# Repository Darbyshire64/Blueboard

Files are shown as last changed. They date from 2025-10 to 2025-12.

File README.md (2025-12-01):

# Blueboard
A Custom ANSI 109 Keyboard. Featuring:   
  - .91inch OLED display
  - Two Potentiomiters
  - 5 Macro Keys

https://blueprint.hackclub.com/projects/1084

## Important Notes About this project
 - If a Component is listed as $0.00 it is already owned by me
 - The BOM says RP2040 But the Schematics say ESP-32 C3 this is because i change mcu mid project however the xiao modules pinout are identical.
 - My Journal.md is outdated but the one on the blueprint project is up todate. the bot seemed to stop updating it automaticly.

### BOM
Alot of these components i or a freind has so i dont need to buy them and i can print the  case my self.

-----------------------------------------
| PRICE | QTY | ITEM |LINK |
|---|-----|---|-----|
| $0.00 | x1  |XIAO RP2040 | |
| $0.00 | x2  |MCP23017 GPIO Expander (SPDIP) | |
| $0.00 | x109| 1N2007 (DO-35 | |
| $0.00 | x2  |Rotary Encoder Switches| |
| $0.00 | x1  |.91inch OLED | |
|-------|-----|--Case-------------|-----|
| $0.00 | x1  |3D Printed Case | |
|------|------|--Key's-------------|-----|
| $24.00| x1  | Key Cap Set | <a href="https://www.aliexpress.com/item/1005007817761888.html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£"> LINK </a> |
| $16.20| x109 | Switches |<a href="https://www.aliexpress.com/item/1005002378701948.html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">LINK </a> |
|$3.68  | x1 | Key Stabalizers Set  | <a href="https://www.aliexpress.com/item/1005004229140548.html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"> LINK </a> |
|-------|------| PCB COSTS --------|------|
|$33.40 | x1 | PCB | |
|$18.63 | x1 | GSDL SHIPING | |
|-$20 | | BP Coupon | |
|-------|------|-------------------|------|
| $75.91 | | TOTAL With Coupon| |
| $95.91 | | TOTAL Without Coupon| |

## Renders
Render2
Render1
Render5
Render4
Render3

## Case






## PCB



## Themeing

Blueboard is Themed and designed to my specific Liking. It features a Blue, Black and Brown Colour scheme. With a Zero RGB Aproach.

#### <a href="https://www.aliexpress.com/item/1005007817761888.html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"> Keycaps </a>


#### <a href="https://www.keyboard-layout-editor.com/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'&_c=%23ab8649&t=%231c3b94&w:2.25%3B&=Enter&_x:3.5&c=%231c3b94&t=%23ab8649%3B&=4%0A%E2%86%90&=5&=6%0A%E2%86%92%3B&@_x:0.25&c=%23cccccc&t=%23000000&a:7%3B&=&_x:0.25&c=%232b2b2b&t=%23ab8649&a:4&w:2.25%3B&=Shift&_c=%231c3b94%3B&=Z&=X&=C&=V&=B&=N&=M&=%3C%0A,&=%3E%0A.&=%3F%0A%2F%2F&_c=%232b2b2b&w:2.75%3B&=Shift&_x:1.25&c=%23ab8649&t=%231c3b94%3B&=%E2%86%91&_x:1.25&c=%231c3b94&t=%23ab8649%3B&=1%0AEnd&=2%0A%E2%86%93&=3%0APgDn&_c=%23ab8649&t=%231c3b94&h:2%3B&=Enter%3B&@_x:0.25&c=%23cccccc&t=%23000000&a:7%3B&=&_x:0.25&c=%232b2b2b&t=%23ab8649&a:4&w:1.25%3B&=Ctrl&_w:1.25%3B&=Win&_w:1.25%3B&=Alt&_c=%23ab8649&t=%231c3b94&a:7&w:6.25%3B&=&_c=%232b2b2b&t=%23ab8649&a:4&w:1.25%3B&=Alt&_w:1.25%3B&=Win&_w:1.25%3B&=Menu&_w:1.25%3B&=Ctrl&_x:0.25&c=%23ab8649&t=%231c3b94%3B&=%E2%86%90&=%E2%86%93&=%E2%86%92&_x:0.25&c=%231c3b94&t=%23ab8649&w:2%3B&=0%0AIns&=.%0ADel"> Key Layout </a> 
keyboard-layout(2)
blueboard



## To Do
  - [X] PCB
    - [X] Deisign Schematic
      - [X] Switches
      - [X] RGB
      - [X] OLED
      - [X] Potentomiters
      - [X] MCU
      - [X] GPIO Expander 
    - [X] Design PCB
    - [X] Add Artwork
  - [ ] Export BOM to CSV
  - [X] Design Case
  - [X] Complete BOM
  - [ ] Write Skeleton Firmware (KMK)

497498089-6dd5f2bd-8309-466f-af9c-b98fabe8da96

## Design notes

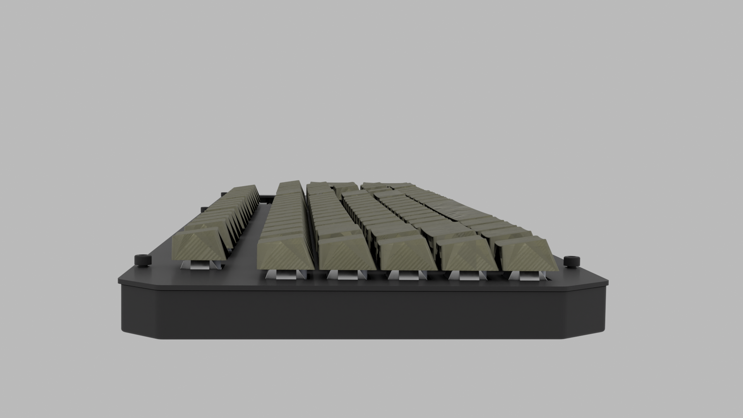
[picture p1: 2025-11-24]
Assets/Render/Render4.png

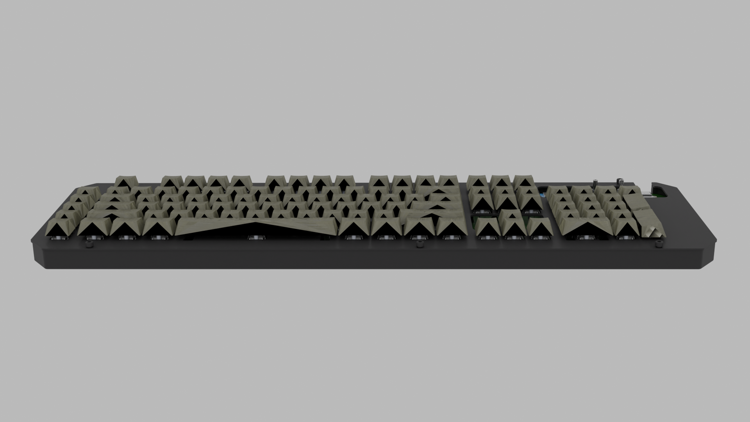
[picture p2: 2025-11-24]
Assets/Render/Render3.png

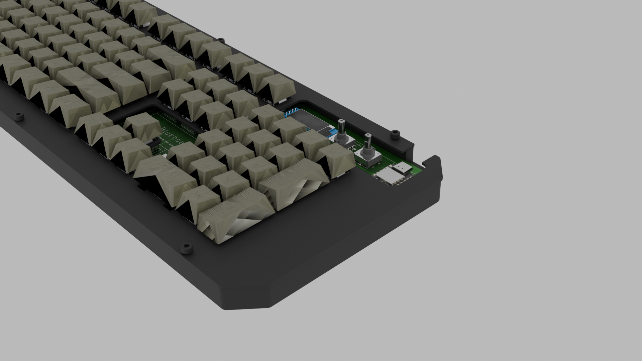
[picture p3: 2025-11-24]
Assets/Render/Render2.png

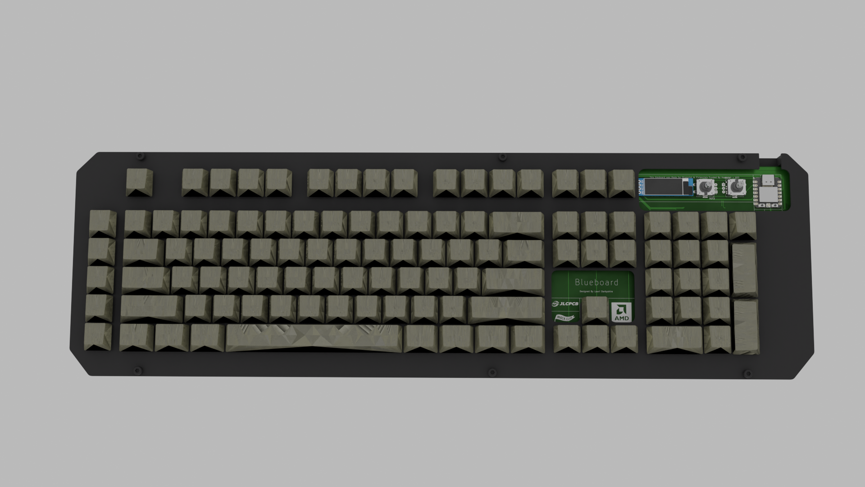
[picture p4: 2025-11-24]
Assets/Render/Render1.png

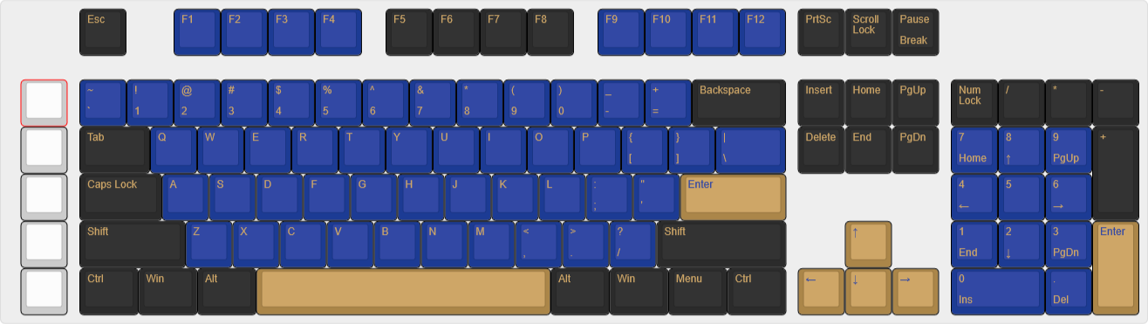
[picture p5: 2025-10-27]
Assets/blueboard-keys-only.png

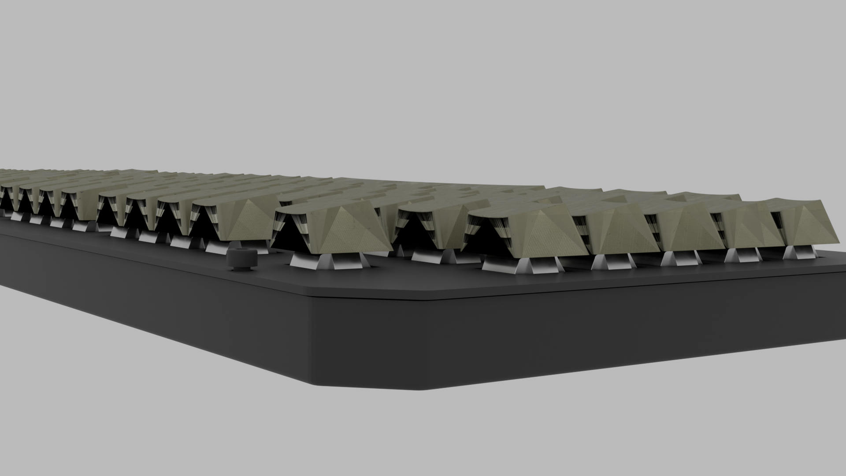
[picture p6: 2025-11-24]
Assets/Render/Render5.png

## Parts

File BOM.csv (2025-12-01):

PRICE | QTY | ITEM | LINK
$0.00 | x1 | XIAO RP2040
$0.00 | x2 | MCP23017 GPIO Expander (SPDIP)
$0.00 | x109 | 1N2007 (DO-35)
$0.00 | x2 | Rotary Encoder Switches
$0.00 | x1 | .91inch OLED
$0.00 | x1 | 3D Printed Case
$24.00 | x1 | Key Cap Set | https://www.aliexpress.com/item/1005007817761888.html
$16.20 | x109 | Switches | https://www.aliexpress.com/item/1005002378701948.html
$3.68 | x1 | Key Stabalizers Set | https://www.aliexpress.com/item/1005004229140548.html
$33.40 | x1 | PCB
$18.63 | x1 | GSDL SHIPING
-$20 |  | BP Coupon
$75.91 |  | TOTAL With Coupon
$95.91 |  | TOTAL Without Coupon

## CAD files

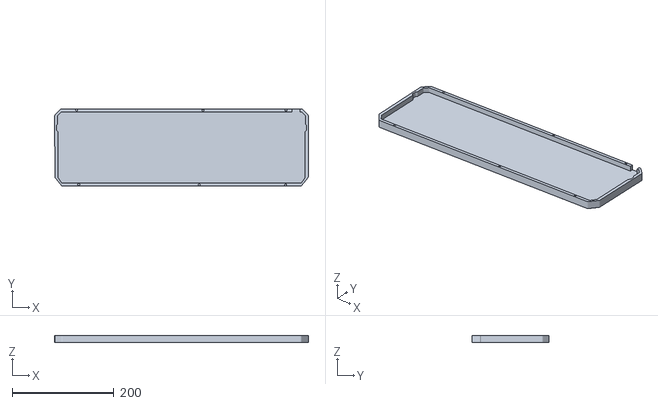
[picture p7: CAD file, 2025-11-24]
Case/CaseBottom.stl
499.5 x 152.0 x 14.7

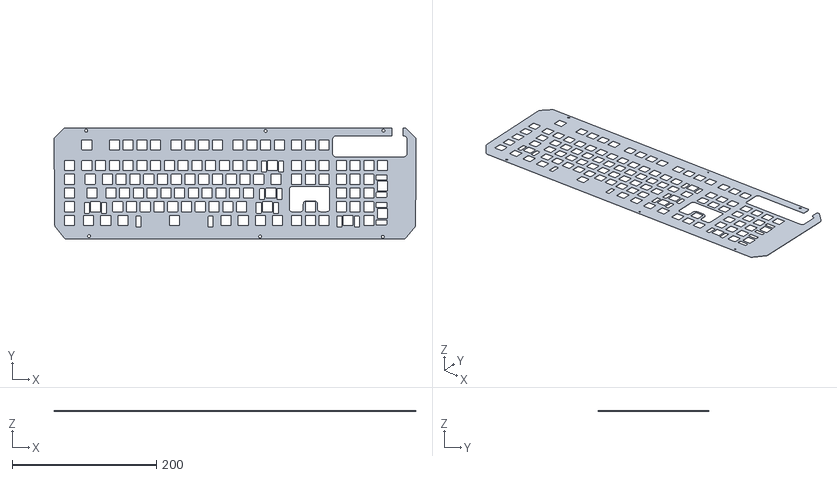
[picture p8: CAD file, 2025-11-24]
Case/Plate.stl
501.5 x 153.7 x 1.50

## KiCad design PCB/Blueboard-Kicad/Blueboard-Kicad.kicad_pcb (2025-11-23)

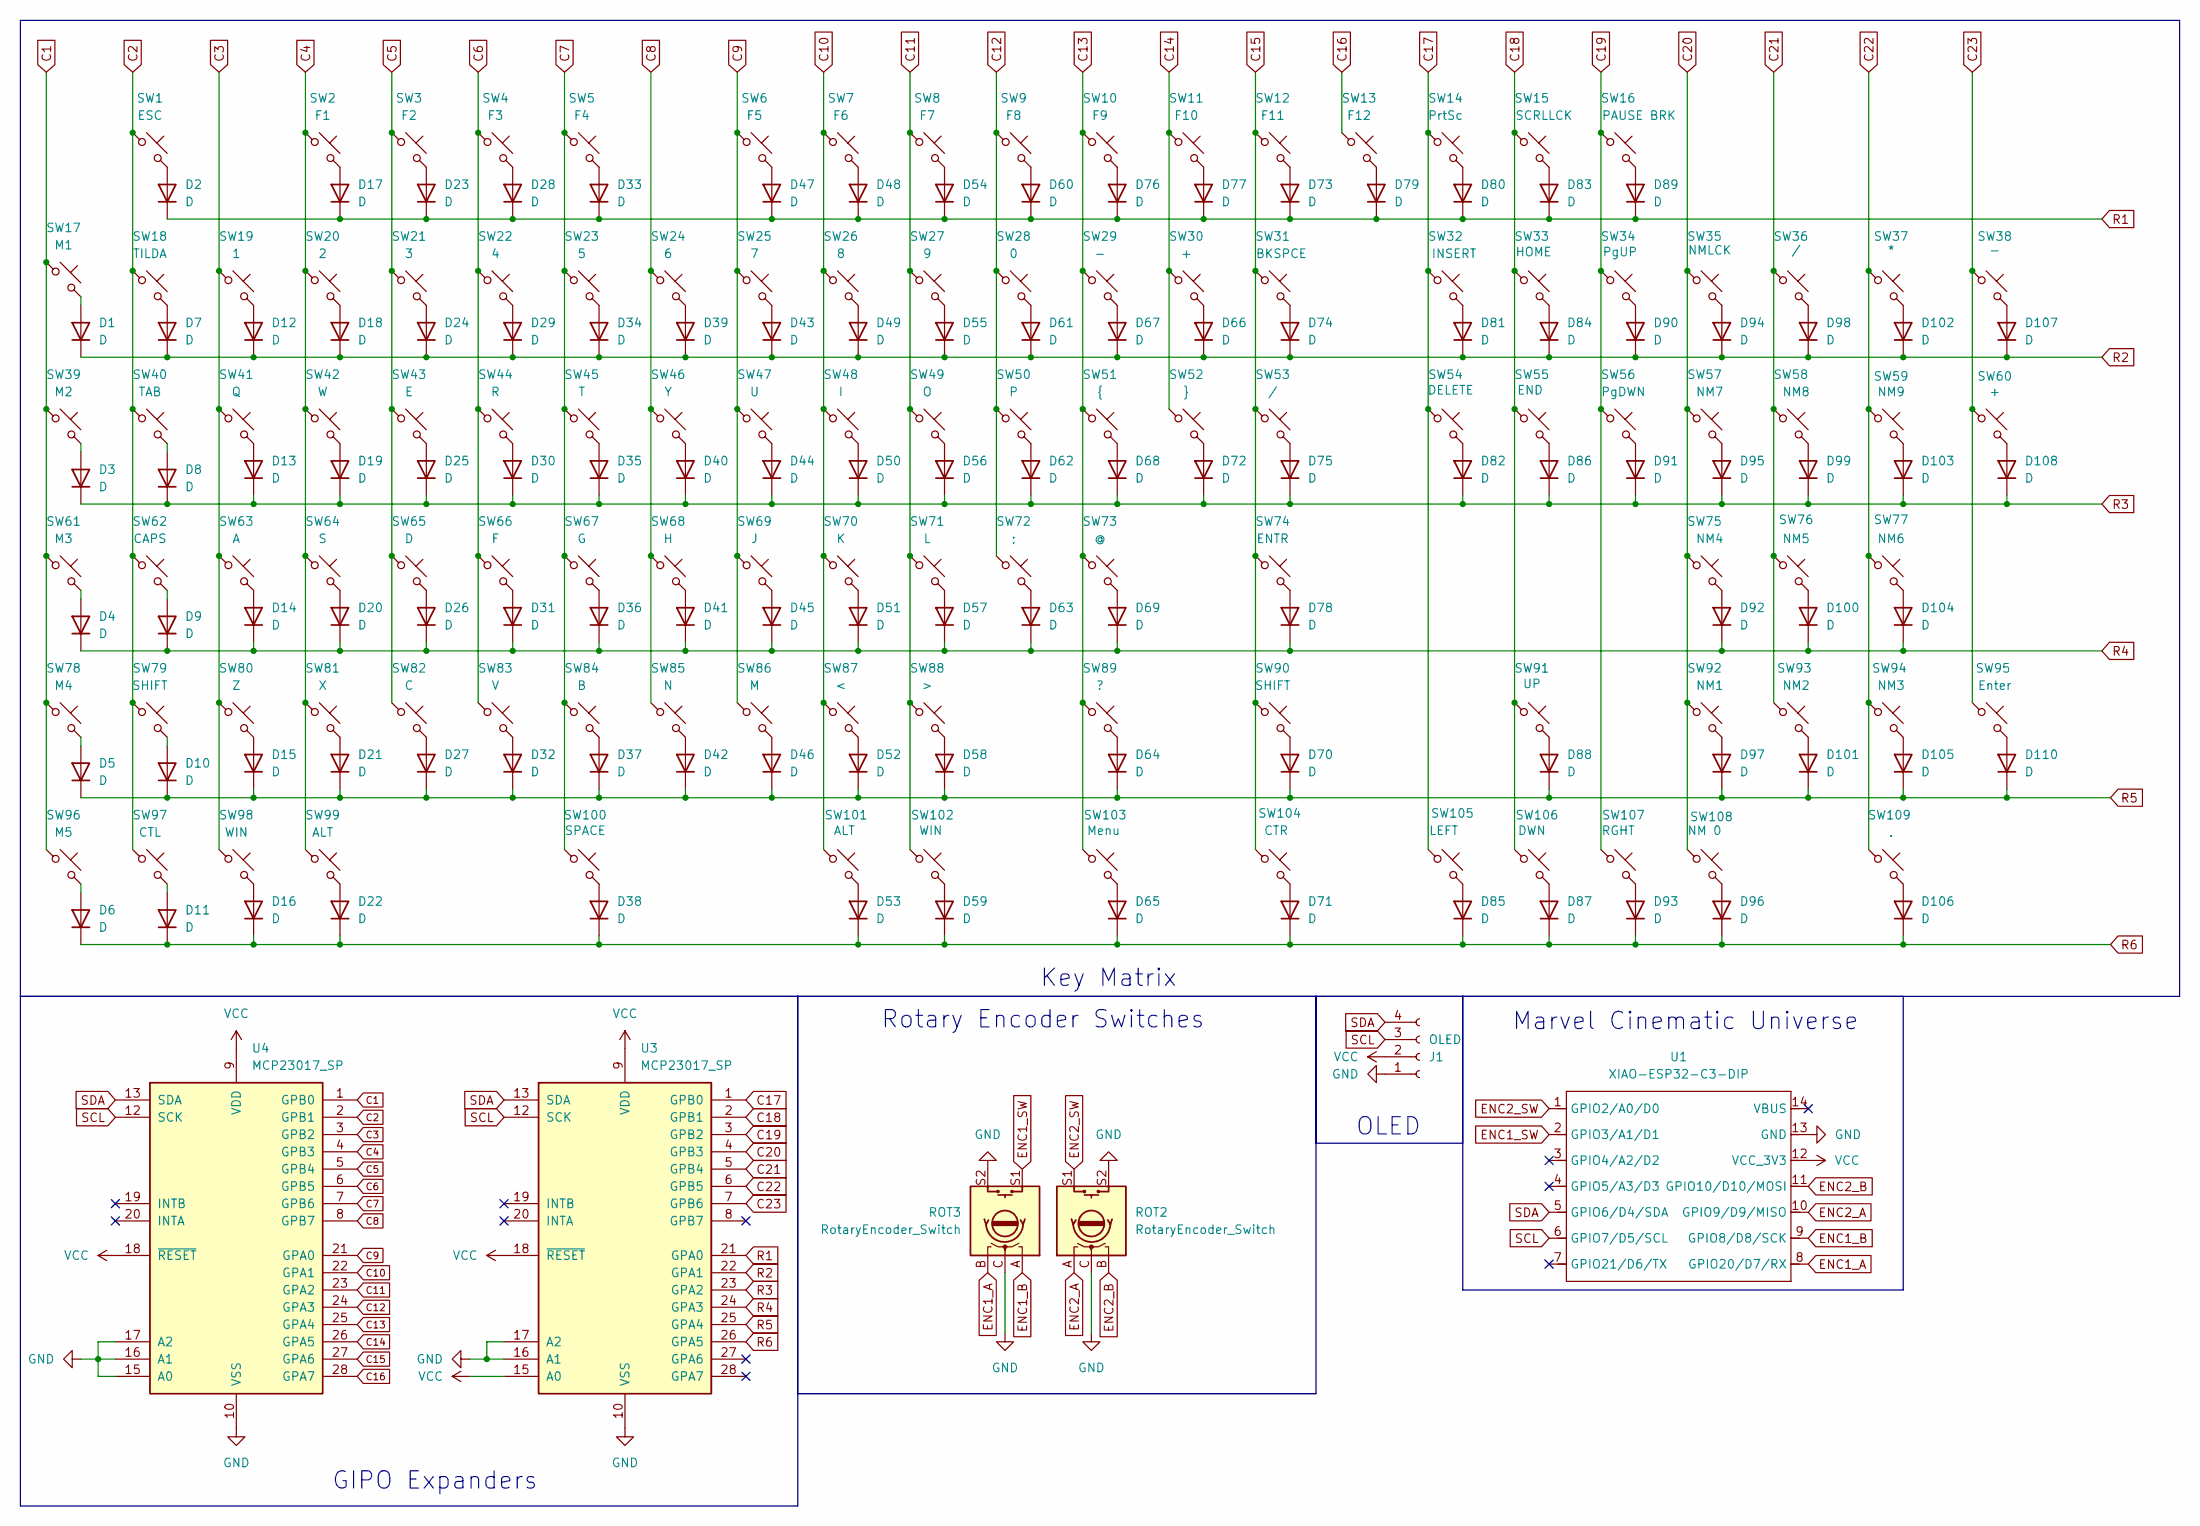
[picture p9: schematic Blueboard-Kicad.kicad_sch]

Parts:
D1, D2, D3, D4, D5, D6, D7, D8, D9, D10, D11, D12, D13, D14, D15, D16, D17, D18, D19, D20, D21, D22, D23, D24, D25, D26, D27, D28, D29, D30, D31, D32, D33, D34, D35, D36, D37, D38, D39, D40, D41, D42, D43, D44, D45, D46, D47, D48, D49, D50, D51, D52, D53, D54, D55, D56, D57, D58, D59, D60, D61, D62, D63, D64, D65, D66, D67, D68, D69, D70, D71, D72, D73, D74, D75, D76, D77, D78, D79, D80, D81, D82, D83, D84, D85, D86, D87, D88, D89, D90, D91, D92, D93, D94, D95, D96, D97, D98, D99, D100, D101, D102, D103, D104, D105, D106, D107, D108, D110: D; D_DO-41_SOD81_P7.62mm_Horizontal
J1: OLED; SSD1306-0.91-OLED-4pin-128x32
ROT2, ROT3: RotaryEncoder_Switch; RotaryEncoder_Alps_EC11E-Switch_Vertical_H20mm_MountingHoles
SW1: ESC; SW_Cherry_MX1A_1.00u_PCB
SW2: F1; SW_Cherry_MX1A_1.00u_PCB
SW3: F2; SW_Cherry_MX1A_1.00u_PCB
SW4: F3; SW_Cherry_MX1A_1.00u_PCB
SW5: F4; SW_Cherry_MX1A_1.00u_PCB
SW6: F5; SW_Cherry_MX1A_1.00u_PCB
SW7: F6; SW_Cherry_MX1A_1.00u_PCB
SW8: F7; SW_Cherry_MX1A_1.00u_PCB
SW9: F8; SW_Cherry_MX1A_1.00u_PCB
SW10: F9; SW_Cherry_MX1A_1.00u_PCB
SW11: F10; SW_Cherry_MX1A_1.00u_PCB
SW12: F11; SW_Cherry_MX1A_1.25u_PCB
SW13: F12; SW_Cherry_MX1A_1.00u_PCB
SW14: PrtSc; SW_Cherry_MX1A_1.00u_PCB
SW15: SCRLLCK; SW_Cherry_MX1A_1.00u_PCB
SW16: PAUSE BRK; SW_Cherry_MX1A_1.00u_PCB
SW17: M1; SW_Cherry_MX1A_1.00u_PCB
SW18: TILDA; SW_Cherry_MX1A_1.00u_PCB
SW19: 1; SW_Cherry_MX1A_1.00u_PCB
SW20: 2; SW_Cherry_MX1A_1.00u_PCB
SW21: 3; SW_Cherry_MX1A_1.00u_PCB
SW22: 4; SW_Cherry_MX1A_1.00u_PCB
SW23: 5; SW_Cherry_MX1A_1.00u_PCB
SW24: 6; SW_Cherry_MX1A_1.00u_PCB
SW25: 7; SW_Cherry_MX1A_1.00u_PCB
SW26: 8; SW_Cherry_MX1A_1.00u_PCB
SW27: 9; SW_Cherry_MX1A_1.00u_PCB
SW28: 0; SW_Cherry_MX1A_1.00u_PCB
SW29, SW38: -; SW_Cherry_MX1A_1.00u_PCB
SW30: +; SW_Cherry_MX1A_1.00u_PCB
SW31: BKSPCE; SW_Cherry_MX1A_2.00u_PCB
SW32: INSERT; SW_Cherry_MX1A_1.00u_PCB
SW33: HOME; SW_Cherry_MX1A_1.00u_PCB
SW34: PgUP; SW_Cherry_MX1A_1.00u_PCB
SW35: NMLCK; SW_Cherry_MX1A_1.00u_PCB
SW36: /; SW_Cherry_MX1A_1.00u_PCB
SW37: *; SW_Cherry_MX1A_1.00u_PCB
SW39: M2; SW_Cherry_MX1A_1.00u_PCB
SW40: TAB; SW_Cherry_MX1A_1.50u_PCB
SW41: Q; SW_Cherry_MX1A_1.00u_PCB
SW42: W; SW_Cherry_MX1A_1.00u_PCB
SW43: E; SW_Cherry_MX1A_1.00u_PCB
SW44: R; SW_Cherry_MX1A_1.00u_PCB
SW45: T; SW_Cherry_MX1A_1.00u_PCB
SW46: Y; SW_Cherry_MX1A_1.00u_PCB
SW47: U; SW_Cherry_MX1A_1.00u_PCB
SW48: I; SW_Cherry_MX1A_1.00u_PCB
SW49: O; SW_Cherry_MX1A_1.00u_PCB
SW50: P; SW_Cherry_MX1A_1.00u_PCB
SW51: {; SW_Cherry_MX1A_1.00u_PCB
SW52: }; SW_Cherry_MX1A_1.00u_PCB
SW53: /; SW_Cherry_MX1A_1.25u_PCB
SW54: DELETE; SW_Cherry_MX1A_1.00u_PCB
SW55: END; SW_Cherry_MX1A_1.00u_PCB
SW56: PgDWN; SW_Cherry_MX1A_1.00u_PCB
SW57: NM7; SW_Cherry_MX1A_1.00u_PCB
SW58: NM8; SW_Cherry_MX1A_1.00u_PCB
SW59: NM9; SW_Cherry_MX1A_1.00u_PCB
SW60: +; SW_Cherry_MX1A_2.00u_Vertical_PCB
SW61: M3; SW_Cherry_MX1A_1.00u_PCB
SW62: CAPS; SW_Cherry_MX1A_1.75u_PCB
SW63: A; SW_Cherry_MX1A_1.00u_PCB
SW64: S; SW_Cherry_MX1A_1.00u_PCB
SW65: D; SW_Cherry_MX1A_1.00u_PCB
SW66: F; SW_Cherry_MX1A_1.00u_PCB
SW67: G; SW_Cherry_MX1A_1.00u_PCB
SW68: H; SW_Cherry_MX1A_1.00u_PCB
SW69: J; SW_Cherry_MX1A_1.00u_PCB
SW70: K; SW_Cherry_MX1A_1.00u_PCB
SW71: L; SW_Cherry_MX1A_1.00u_PCB
SW72: ;; SW_Cherry_MX1A_1.00u_PCB
SW73: @; SW_Cherry_MX1A_1.00u_PCB
SW74: ENTR; SW_Cherry_MX1A_2.25u_PCB
SW75: NM4; SW_Cherry_MX1A_1.00u_PCB
SW76: NM5; SW_Cherry_MX1A_1.00u_PCB
SW77: NM6; SW_Cherry_MX1A_1.00u_PCB
SW78: M4; SW_Cherry_MX1A_1.00u_PCB
SW79: SHIFT; SW_Cherry_MX1A_2.25u_PCB
SW80: Z; SW_Cherry_MX1A_1.00u_PCB
SW81: X; SW_Cherry_MX1A_1.00u_PCB
SW82: C; SW_Cherry_MX1A_1.00u_PCB
SW83: V; SW_Cherry_MX1A_1.00u_PCB
SW84: B; SW_Cherry_MX1A_1.00u_PCB
SW85: N; SW_Cherry_MX1A_1.00u_PCB
SW86: M; SW_Cherry_MX1A_1.00u_PCB
SW87: <; SW_Cherry_MX1A_1.00u_PCB
SW88: >; SW_Cherry_MX1A_1.00u_PCB
SW89: ?; SW_Cherry_MX1A_1.00u_PCB
SW90: SHIFT; SW_Cherry_MX1A_2.75u_PCB
SW91: UP; SW_Cherry_MX1A_1.00u_PCB
SW92: NM1; SW_Cherry_MX1A_1.00u_PCB
SW93: NM2; SW_Cherry_MX1A_1.00u_PCB
SW94: NM3; SW_Cherry_MX1A_1.00u_PCB
SW95: Enter; SW_Cherry_MX1A_2.00u_Vertical_PCB
SW96: M5; SW_Cherry_MX1A_1.00u_PCB
SW97: CTL; SW_Cherry_MX1A_1.25u_PCB
SW98, SW102: WIN; SW_Cherry_MX1A_1.25u_PCB
SW99, SW101: ALT; SW_Cherry_MX1A_1.25u_PCB
SW100: SPACE; SW_Cherry_MX1A_6.25u_PCB
SW103: Menu; SW_Cherry_MX1A_1.25u_PCB
SW104: CTR; SW_Cherry_MX1A_1.25u_PCB
SW105: LEFT; SW_Cherry_MX1A_1.00u_PCB
SW106: DWN; SW_Cherry_MX1A_1.00u_PCB
SW107: RGHT; SW_Cherry_MX1A_1.00u_PCB
SW108: NM 0; SW_Cherry_MX1A_2.00u_PCB
SW109: .; SW_Cherry_MX1A_1.00u_PCB
U1: XIAO-ESP32-C3-DIP; XIAO-ESP32C3-DIP
U3, U4: MCP23017_SP; DIP-28_W7.62mm

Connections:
C1: SW17.1, SW39.1, SW61.1, SW78.1, SW96.1, U4.1 (GPB0)
C2: SW1.1, SW18.1, SW40.1, SW62.1, SW79.1, SW97.1, U4.2 (GPB1)
C3: SW19.1, SW41.1, SW63.1, SW80.1, SW98.1, U4.3 (GPB2)
C4: SW2.1, SW20.1, SW42.1, SW64.1, SW81.1, SW99.1, U4.4 (GPB3)
C5: SW3.1, SW21.1, SW43.1, SW65.1, SW82.1, U4.5 (GPB4)
C6: SW4.1, SW22.1, SW44.1, SW66.1, SW83.1, U4.6 (GPB5)
C7: SW5.1, SW23.1, SW45.1, SW67.1, SW84.1, SW100.1, U4.7 (GPB6)
C8: SW24.1, SW46.1, SW68.1, SW85.1, U4.8 (GPB7)
C9: SW6.1, SW25.1, SW47.1, SW69.1, SW86.1, U4.21 (GPA0)
C10: SW7.1, SW26.1, SW48.1, SW70.1, SW87.1, SW101.1, U4.22 (GPA1)
C11: SW8.1, SW27.1, SW49.1, SW71.1, SW88.1, SW102.1, U4.23 (GPA2)
C12: SW9.1, SW28.1, SW50.1, SW72.1, U4.24 (GPA3)
C13: SW10.1, SW29.1, SW51.1, SW73.1, SW89.1, SW103.1, U4.25 (GPA4)
C14: SW11.1, SW30.1, SW52.1, U4.26 (GPA5)
C15: SW12.1, SW31.1, SW53.1, SW74.1, SW90.1, SW104.1, U4.27 (GPA6)
C16: SW13.1, U4.28 (GPA7)
C17: SW14.1, SW32.1, SW54.1, SW105.1, U3.1 (GPB0)
C18: SW15.1, SW33.1, SW55.1, SW91.1, SW106.1, U3.2 (GPB1)
C19: SW16.1, SW34.1, SW56.1, SW107.1, U3.3 (GPB2)
C20: SW35.1, SW57.1, SW75.1, SW92.1, SW108.1, U3.4 (GPB3)
C21: SW36.1, SW58.1, SW76.1, SW93.1, U3.5 (GPB4)
C22: SW37.1, SW59.1, SW77.1, SW94.1, SW109.1, U3.6 (GPB5)
C23: SW38.1, SW60.1, SW95.1, U3.7 (GPB6)
ENC1_A: ROT3.B, U1.8 (GPIO20/D7/RX)
ENC1_B: ROT3.A, U1.9 (GPIO8/D8/SCK)
ENC1_SW: ROT3.S1, U1.2 (GPIO3/A1/D1)
ENC2_A: ROT2.A, U1.10 (GPIO9/D9/MISO)
ENC2_B: ROT2.B, U1.11 (GPIO10/D10/MOSI)
ENC2_SW: ROT2.S1, U1.1 (GPIO2/A0/D0)
GND: J1.1, ROT2.C, ROT2.S2, ROT3.C, ROT3.S2, U1.13 (GND), U3.10 (VSS), U3.16 (A1), U3.17 (A2), U4.10 (VSS), U4.15 (A0), U4.16 (A1), U4.17 (A2)
unnamed: D1.2 (A), SW17.2
unnamed: D2.2 (A), SW1.2
unnamed: D3.2 (A), SW39.2
unnamed: D4.2 (A), SW61.2
unnamed: D5.2 (A), SW78.2
unnamed: D6.2 (A), SW96.2
unnamed: D7.2 (A), SW18.2
unnamed: D8.2 (A), SW40.2
unnamed: D9.2 (A), SW62.2
unnamed: D10.2 (A), SW79.2
unnamed: D11.2 (A), SW97.2
unnamed: D12.2 (A), SW19.2
unnamed: D13.2 (A), SW41.2
unnamed: D14.2 (A), SW63.2
unnamed: D15.2 (A), SW80.2
unnamed: D16.2 (A), SW98.2
unnamed: D17.2 (A), SW2.2
unnamed: D18.2 (A), SW20.2
unnamed: D19.2 (A), SW42.2
unnamed: D20.2 (A), SW64.2
unnamed: D21.2 (A), SW81.2
unnamed: D22.2 (A), SW99.2
unnamed: D23.2 (A), SW3.2
unnamed: D24.2 (A), SW21.2
unnamed: D25.2 (A), SW43.2
unnamed: D26.2 (A), SW65.2
unnamed: D27.2 (A), SW82.2
unnamed: D28.2 (A), SW4.2
unnamed: D29.2 (A), SW22.2
unnamed: D30.2 (A), SW44.2
unnamed: D31.2 (A), SW66.2
unnamed: D32.2 (A), SW83.2
unnamed: D33.2 (A), SW5.2
unnamed: D34.2 (A), SW23.2
unnamed: D35.2 (A), SW45.2
unnamed: D36.2 (A), SW67.2
unnamed: D37.2 (A), SW84.2
unnamed: D38.2 (A), SW100.2
unnamed: D39.2 (A), SW24.2
unnamed: D40.2 (A), SW46.2
unnamed: D41.2 (A), SW68.2
unnamed: D42.2 (A), SW85.2
unnamed: D43.2 (A), SW25.2
unnamed: D44.2 (A), SW47.2
unnamed: D45.2 (A), SW69.2
unnamed: D46.2 (A), SW86.2
unnamed: D47.2 (A), SW6.2
unnamed: D48.2 (A), SW7.2
unnamed: D49.2 (A), SW26.2
unnamed: D50.2 (A), SW48.2
unnamed: D51.2 (A), SW70.2
unnamed: D52.2 (A), SW87.2
unnamed: D53.2 (A), SW101.2
unnamed: D54.2 (A), SW8.2
unnamed: D55.2 (A), SW27.2
unnamed: D56.2 (A), SW49.2
unnamed: D57.2 (A), SW71.2
unnamed: D58.2 (A), SW88.2
unnamed: D59.2 (A), SW102.2
unnamed: D60.2 (A), SW9.2
unnamed: D61.2 (A), SW28.2
unnamed: D62.2 (A), SW50.2
unnamed: D63.2 (A), SW72.2
unnamed: D64.2 (A), SW89.2
unnamed: D65.2 (A), SW103.2
unnamed: D66.2 (A), SW30.2
unnamed: D67.2 (A), SW29.2
unnamed: D68.2 (A), SW51.2
unnamed: D69.2 (A), SW73.2
unnamed: D70.2 (A), SW90.2
unnamed: D71.2 (A), SW104.2
unnamed: D72.2 (A), SW52.2
unnamed: D73.2 (A), SW12.2
unnamed: D74.2 (A), SW31.2
unnamed: D75.2 (A), SW53.2
unnamed: D76.2 (A), SW10.2
unnamed: D77.2 (A), SW11.2
unnamed: D78.2 (A), SW74.2
unnamed: D79.2 (A), SW13.2
unnamed: D80.2 (A), SW14.2
unnamed: D81.2 (A), SW32.2
unnamed: D82.2 (A), SW54.2
unnamed: D83.2 (A), SW15.2
unnamed: D84.2 (A), SW33.2
unnamed: D85.2 (A), SW105.2
unnamed: D86.2 (A), SW55.2
unnamed: D87.2 (A), SW106.2
unnamed: D88.2 (A), SW91.2
unnamed: D89.2 (A), SW16.2
unnamed: D90.2 (A), SW34.2
unnamed: D91.2 (A), SW56.2
unnamed: D92.2 (A), SW75.2
unnamed: D93.2 (A), SW107.2
unnamed: D94.2 (A), SW35.2
unnamed: D95.2 (A), SW57.2
unnamed: D96.2 (A), SW108.2
unnamed: D97.2 (A), SW92.2
unnamed: D98.2 (A), SW36.2
unnamed: D99.2 (A), SW58.2
unnamed: D100.2 (A), SW76.2
unnamed: D101.2 (A), SW93.2
unnamed: D102.2 (A), SW37.2
unnamed: D103.2 (A), SW59.2
unnamed: D104.2 (A), SW77.2
unnamed: D105.2 (A), SW94.2
unnamed: D106.2 (A), SW109.2
unnamed: D107.2 (A), SW38.2
unnamed: D108.2 (A), SW60.2
unnamed: D110.2 (A), SW95.2
R1: D2.1 (K), D17.1 (K), D23.1 (K), D28.1 (K), D33.1 (K), D47.1 (K), D48.1 (K), D54.1 (K), D60.1 (K), D73.1 (K), D76.1 (K), D77.1 (K), D79.1 (K), D80.1 (K), D83.1 (K), D89.1 (K), U3.21 (GPA0)
R2: D1.1 (K), D7.1 (K), D12.1 (K), D18.1 (K), D24.1 (K), D29.1 (K), D34.1 (K), D39.1 (K), D43.1 (K), D49.1 (K), D55.1 (K), D61.1 (K), D66.1 (K), D67.1 (K), D74.1 (K), D81.1 (K), D84.1 (K), D90.1 (K), D94.1 (K), D98.1 (K), D102.1 (K), D107.1 (K), U3.22 (GPA1)
R3: D3.1 (K), D8.1 (K), D13.1 (K), D19.1 (K), D25.1 (K), D30.1 (K), D35.1 (K), D40.1 (K), D44.1 (K), D50.1 (K), D56.1 (K), D62.1 (K), D68.1 (K), D72.1 (K), D75.1 (K), D82.1 (K), D86.1 (K), D91.1 (K), D95.1 (K), D99.1 (K), D103.1 (K), D108.1 (K), U3.23 (GPA2)
R4: D4.1 (K), D9.1 (K), D14.1 (K), D20.1 (K), D26.1 (K), D31.1 (K), D36.1 (K), D41.1 (K), D45.1 (K), D51.1 (K), D57.1 (K), D63.1 (K), D69.1 (K), D78.1 (K), D92.1 (K), D100.1 (K), D104.1 (K), U3.24 (GPA3)
R5: D5.1 (K), D10.1 (K), D15.1 (K), D21.1 (K), D27.1 (K), D32.1 (K), D37.1 (K), D42.1 (K), D46.1 (K), D52.1 (K), D58.1 (K), D64.1 (K), D70.1 (K), D88.1 (K), D97.1 (K), D101.1 (K), D105.1 (K), D110.1 (K), U3.25 (GPA4)
R6: D6.1 (K), D11.1 (K), D16.1 (K), D22.1 (K), D38.1 (K), D53.1 (K), D59.1 (K), D65.1 (K), D71.1 (K), D85.1 (K), D87.1 (K), D93.1 (K), D96.1 (K), D106.1 (K), U3.26 (GPA5)
SCL: J1.3, U1.6 (GPIO7/D5/SCL), U3.12 (SCK), U4.12 (SCK)
SDA: J1.4, U1.5 (GPIO6/D4/SDA), U3.13 (SDA), U4.13 (SDA)
VCC: J1.2, U1.12 (VCC_3V3), U3.9 (VDD), U3.15 (A0), U3.18 (~RESET), U4.9 (VDD), U4.18 (~RESET)

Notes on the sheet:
Key Matrix
OLED
GIPO Expanders
Marvel Cinematic Universe
Rotary Encoder Switches

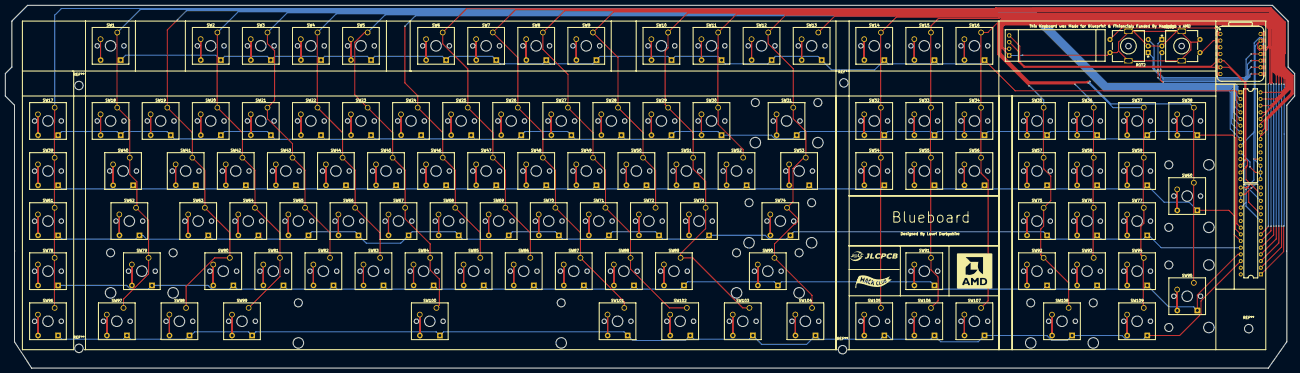
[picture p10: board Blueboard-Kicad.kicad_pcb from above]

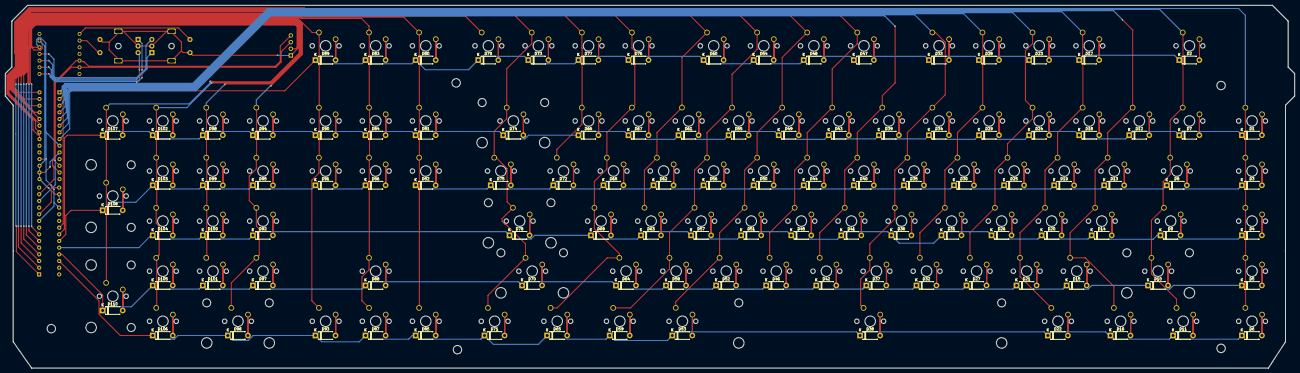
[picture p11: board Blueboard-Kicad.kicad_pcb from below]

Board: 2 copper layers, 490.5 x 138.0 mm, 224 parts (109 on the bottom side), 148 nets.

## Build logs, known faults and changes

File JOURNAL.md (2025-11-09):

<!--
  ===================    !!READ THIS NOTICE!!   ====================
  DO NOT edit this file manually. Your changes WILL BE OVERWRITTEN!
  This journal is auto generated and updated by Hack Club Blueprint.
  To edit this file, please edit your journal entries on Blueprint.
  ==================================================================
-->

## 10/27/2025 - Research + Keymatrix  

 Today i spent around 2 Hours Doing Research on the specific key set i would like to do. seting up the github repository and planning what i would like to do. 

These are the Keycaps i would like to use from Ali Express.


Then i spent the rest of my time Doing the most Repetitive and irritatingly complex task the Keyboard Matrix Schematic. This is Quite literaly my most complex and messy schematic.



## 10/29/2025 - Finished Schematic and Layed Out Components On PCB  

Today i spend aroud 4 Hours Finsihing off the Schematic and Deciding what GPIO Expander to use. I was initialy going to use the TCA9539PWR From Texas Instruments But after researching that didnt have any support with the KMK firmware so in the end i used the MCP23017.  I also learnt about how Rotary Encoder Switches work and added 2 to the schematic. 

#### Schematic

#### TCA9539PWR
Texas Instruments_TCA9539PWR_3940
#### MCP23017


## Working On the PCB
Then i Asigned all the footprints and started work on the PCB. i aranged all the Keys, OLED and Rotary Encoders. 


## 11/9/2025 - Routing the PCB  

I started my decent into routing hell. how do pepole route keyboards Ive atached an immage of my atempt at hell. Im thinking i might need to make this a 6 layer pcb but the price would skyrocket 



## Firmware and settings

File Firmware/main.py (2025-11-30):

print("KMK Starting")

#Base Modules
import time

# Get KMK Modules
import board, busio

from kmk.kmk_keyboard import KMKKeyboard
from kmk.keys import KC
from kmk.scanners import DiodeOrientation

# Get Exstentions for Other Components
from kmk.extensions.modules.encoder import EncoderHandler
from kmk.extensions.display import Display, SSD1306
from adafruit_mcp230xx.mcp23017 import MCP23017

print("[STAUTS] Import Done")

## Start Main Code
print("[STAUTS] Expander Init")

i2c = busio.I2C(board.SCL, board.SDA)

mcp1 = MCP23017(i2c, address=0x20)
mcp2 = MCP23017(i2c, address=0x21)

# EXPANDER 1 - COL
col1 = mcp1.get_pin(0)
col2 = mcp1.get_pin(1)
col3 = mcp1.get_pin(2)
col4 = mcp1.get_pin(3)
col5 = mcp1.get_pin(4)
col6 = mcp1.get_pin(5)
col7 = mcp1.get_pin(6)
col8 = mcp1.get_pin(7)
col9 = mcp1.get_pin(8)
col10 = mcp1.get_pin(9)
col11 = mcp1.get_pin(10)
col12 = mcp1.get_pin(11)
col13 = mcp1.get_pin(12)
col14 = mcp1.get_pin(13)
col15 = mcp1.get_pin(14)
col16 = mcp1.get_pin(15)
col17 = mcp1.get_pin(16)

# EXPANDER 2 - COL
col18 = mcp2.get_pin(0)
col19 = mcp2.get_pin(1)
col20 = mcp2.get_pin(2)
col21 = mcp2.get_pin(3)
col22 = mcp2.get_pin(4)
col23 = mcp2.get_pin(5)


# EXPANDER 2 - ROW
row1 = mcp2.get_pin(8)
row2 = mcp2.get_pin(9)
row3 = mcp2.get_pin(10)
row4 = mcp2.get_pin(11)
row5 = mcp2.get_pin(12)
row6 = mcp2.get_pin(13)

print("[STAUTS] Expander Done")
print("[STAUTS] Keyboard Init")

keyboard = KMKKeyboard()

keyboard.col_pins = (col1,col2,col3,col4,col5,col6,col7,col8,col9,col10,col11,col12,col13,col14,col15,col16,col16,col17,col18,col19,col20,col21,col22,col23) 
keyboard.row_pins = (row1,row2,row3,row4,row5,row6)
keyboard.diode_orientation = DiodeOrientation.COL2ROW

keyboard.keymap = [
    [XXXXX],[KC.ESCAPE],[XXXXX],[KC.F1],[KC.F2],[KC.F3],[KC.F4],[XXXXX],[KC.F5],[KC.F6],[KC.F7],[KC.F8],[KC.F9],[KC.F10],[KC.F11],[KC.F12],[KC.PSCREEN],[KC.SCROLLLOCK],[KC.PAUSE],[XXXXX],[XXXXX],[XXXXX],[XXXXX]
    [KC.N1],[KC.ZKHK],[KC.N1],[KC.N2],[KC.N3],[KC.N4],[KC.N5],[KC.N6],[KC.N7],[KC.N8],[KC.N9],[KC.N0],[KC.MINUS],[KC.PLUS],[KC.BSPACE],[XXXXX],[KC.INSERT],[KC.HOME],[KC.PGUP],[KC.NLCK],[KC.KP_SLASH],[KC.PAST],[KC.PMNS]
    [KC.N2],[KC.TAB],[KC.Q],[KC.W],[KC.E],[KC.R],[KC.T],[KC.Y],[KC.D],[KC.I],[KC.O],[KC.P],[KC.LBRACKET],[LBRACKET],[KC.SLASH],[XXXXX],[KC.DELETE],[KC.END],[KC.PGDOWN],[KC.KP_7],[KC.P8],[KC.P9],[KC.PPLS]
    [KC.N3],[KC.CAPS],[KC.A],[KC.S],[KC.D],[KC.F],[KC.G],[KC.H],[KC.J],[KC.K],[KC.L],[KC.SCOLON],[KC.AT],[XXXXX],[KC.ENTR][XXXXX],[XXXXX],[XXXXX],[XXXXX],[KC.KP_4],[KC.P5],[KC.P6],[XXXXX]
    [KC.N4],[KC.LSHIFT],[KC.Z],[KC.X],[KC.C],[KC.V],[KC.B],[KC.N],[KC.M],[KC.COMM],[KC.DOT],[XXXXX],[XXXXX],[KC.QUES],[XXXXX],[KC.RSHIFT],[XXXXX],[XXXXX],[KC.UP],[XXXXX],[KC.KP_1],[KC.P2],[KC.P3],[KC.PENT]
    [KC.N5],[KC.LCTRL],[KC.LGUI],[KC.LALT],[XXXXX],[XXXXX],[KC.SPACE],[XXXXX],[XXXXX][KC.RALT],[KC.RGUI],[XXXXX],[XXXXX],[XXXXX],[KC.RCTRL][XXXXX],[KC.LEFT],[KC.DOWN],[KC.RIGHT],[KC.KP_0],[XXXXX],[XXXXX]
]

print("[STAUTS] Keyboard Done")
print("[STAUTS] Encoder Init")


encoder_handler = EncoderHandler()
keyboard.modules = [layers, holdtap, encoder_handler]


# Regular GPIO Encoder
encoder_handler.pins = (
    (board.D8, board.D7, board.D1), # encoder #1 
    (board.D11, board.D10, board.D0) # encoder #2
)


encoder_handler.map = [ 
    ( KC.VOLD, KC.VOLU, KC.MUTE),
    (Zoom_out, Zoom_in, KC.NO),
]

print("[STAUTS] Encoder Done")
print("[STAUTS] OLED Init")


oled = SSD1306(
    i2c=board.I2C(),
    width=128,
    height=32
)

display = Display(oled)
keyboard.extensions.append(display)

def log(text):
    display.show_text(text)
    print(text)

log("Hello World!!!")
time.sleep(.5)


log("[STAUTS] OLED Done")
log("[STAUTS] Initialzing")
    

if __name__ == "__main__":
    keyboard.go()

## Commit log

2025-10-27 Completed Key Matrix
    [Blueboard-Kicad.kicad_pcb, Blueboard-Kicad.kicad_sch]
2025-10-28 Updated Schematic With Completed Matrix
    [Blueboard-Kicad.kicad_sch]
2025-10-29 Finished Schematc + Layedout Components
    [Blueboard-Kicad.kicad_pcb, Blueboard-Kicad.kicad_sch]
2025-10-29 Started Adding the Diodes to the PCB
    [Blueboard-Kicad.kicad_pcb, Blueboard-Kicad.kicad_sch]
2025-11-05 Update To Do list with completed schematic tasks
2025-11-10 Made alot of changes to the PCB
    [Blueboard-Kicad.kicad_pcb]
2025-11-11 Finalized PCB
    [Blueboard-Kicad.kicad_pcb]
2025-11-13 Added BOM
    Added BOM
2025-11-13 Mark BOM as complete in README
2025-11-23 Forgot to Commit PCB Changes
    [Blueboard-Kicad-B_Cu.gbr, Blueboard-Kicad-B_Mask.gbr, Blueboard-Kicad-B_Paste.gbr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]
2025-11-24 Worked On Blender Render
    [CaseBottom.stl, Plate.stl]
2025-11-30 Add BOM.csv
    [BOM.csv]
2025-11-30 Reorganised Files and updated Gerber's & F3z file
    [Blueboard-Kicad-B_Cu.gbr, Blueboard-Kicad-B_Mask.gbr, Blueboard-Kicad-B_Paste.gbr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]
2025-12-01 Revise BOM with updated prices and links
    Updated BOM.csv to reflect new pricing and item links.
    [BOM.csv]
